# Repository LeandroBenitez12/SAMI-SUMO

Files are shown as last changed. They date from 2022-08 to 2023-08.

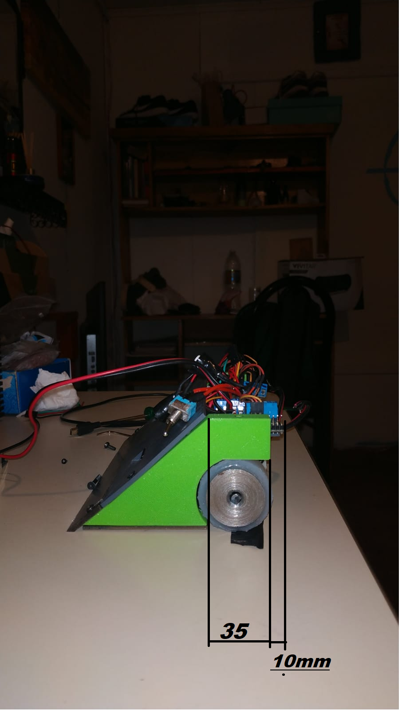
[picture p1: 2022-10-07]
Hardware/Samilateral.png

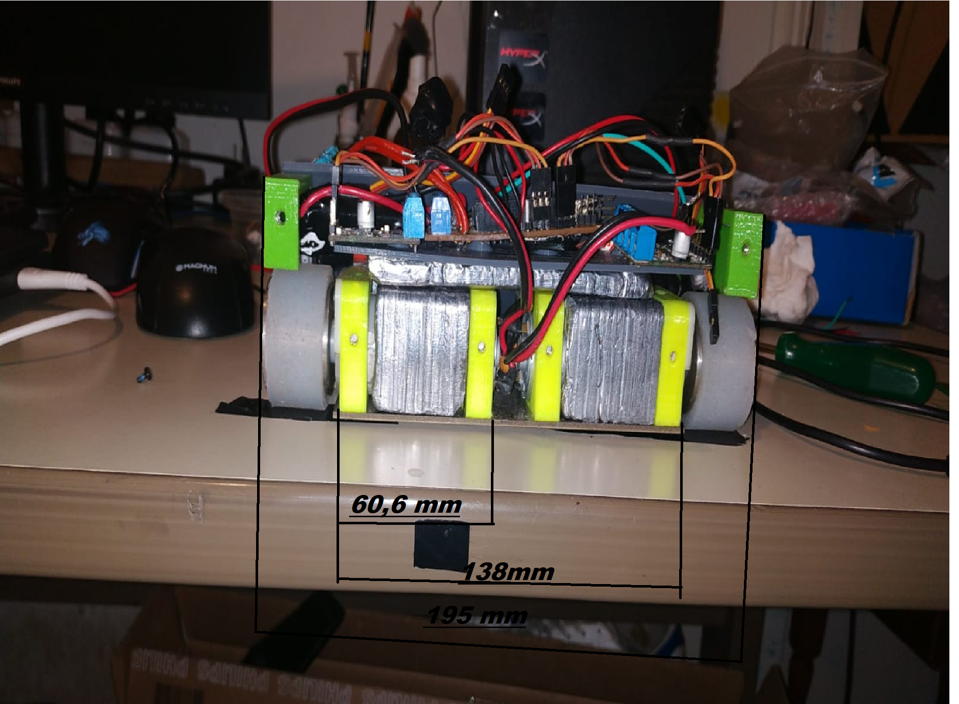
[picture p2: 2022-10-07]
Hardware/Sami.png

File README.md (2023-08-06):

# Robot Sumo Sami 🤖🏆

Sami Robot

## Descripción del Proyecto

Este repositorio contiene el código y los recursos utilizados para el desarrollo de un robot Sumo llamado Sami.

El proyecto fue iniciado en 2022 por un grupo de estudiantes de Robótica del Industrial de Temperley, Buenos Aires, Argentina, entre ellos Leandro Benitez, Ezequiel Sierra, Abril Moyano y Facundo Timwki. Contamos con la invaluable colaboración de nuestro profesor, el Ingeniero Bustos Mariano.

Sami es un robot compacto y bien equilibrado diseñado específicamente para competir en las competencias de robótica, en particular en la Liga Nacional de Robótica (LNR) en Argentina. Durante el proceso de desarrollo, logramos el título de campeones en una competencia de robótica en el Instituto Técnico Nuestra Señora De Itatí, además avanzamos en cuanto a desarrollo personal y grupal, obtuvimos experiencia en la programación, diseño de PCB, 3D, el armado de robots, y fundiendo plomo, entre otras cosas...

## Características del Robot

- **Microcontrolador ESP32** para un rendimiento potente y una amplia capacidad de conectividad.
- **Pantalla OLED** para visualizar menús y estrategias en tiempo real.
- **Drivers Pololu 24v13** para el control preciso de motores y la maniobrabilidad del robot.
- **Sensores Sharp GP2Y0A60SZLF** para detectar obstáculos y oponentes.
- **Sensores de piso QRE1113 SMD y un LDR** utilizados en diversas estrategias de detección.
- Alimentación con **2 baterías LiPo en serie de 3 celdas**, logrando una tensión de 24V.
- Uso de un **convertidor Step-Down** para bajar la tensión y alimentar el microcontrolador.

## Estructura del Repositorio

- **/Software:** Contiene el código de programación en C++ para el robot Sami, basado en el entorno Arduino, y las librerías personalizadas.
- **/Hardware:** Incluye el diseño 3D del robot Sami, así como recursos relacionados con el armado físico y moldeado de plomo para alcanzar el límite de peso en la competencia.

## Instrucciones de Uso

1. Clona el repositorio en tu computadora local para acceder a todos los recursos y el código.
2. Explora el contenido de **/Software** para conocer la programación del robot y las diferentes estrategias disponibles.
3. Consulta el diseño 3D y la información en **/Hardware** para comprender la estructura y los componentes utilizados.

## Cómo Contribuir

¡Valoramos y agradecemos cualquier contribución que puedas brindar para mejorar nuestro robot Sami! Si deseas colaborar, sugerir mejoras o corregir problemas, sigue estos pasos:

1. Haz un fork de este repositorio y clona tu copia localmente.
2. Realiza los cambios y mejoras en tu rama, incluso si es para sugerir posibles soluciones o nuevas ideas.
3. Asegúrate de agregar o actualizar la documentación con tus contribuciones.
4. Realiza un pull request a nuestra rama principal para que podamos revisar y considerar tus aportes.













y videos....

https://github.com/LeandroBenitez12/SAMI_RBSUMO/assets/108737751/56b0725f-8328-4741-986b-e7431d0c3679

## Contacto

¡Nos encantaría recibir tus comentarios, sugerencias y cualquier tipo de feedback que nos ayude a mejorar nuestro proyecto Sami! Si deseas ponerte en contacto con nosotros, no dudes en escribirnos a:

- Leandro Benitez: leandrobenitezz2004@gmail.com
- Ezequiel Sierra: Sierraezequiel75@gmail.com

## Agradecimientos

Queremos expresar nuestro agradecimiento a todas las personas que nos han brindado apoyo y colaboración en este proyecto. ¡Sin su ayuda, no habríamos llegado tan lejos en el desarrollo de Sami y en nuestras competencias!

¡Estamos entusiasmados con los avances logrados hasta el momento y esperamos seguir mejorando y refinando nuestro robot Sumo Sami en el futuro! 🤖🏆

¡Gracias por tu interés en nuestro proyecto! Si necesitas más información o tienes otras preguntas, no dudes en hacérmelas. ¡Éxito en tus futuras competencias de robótica!

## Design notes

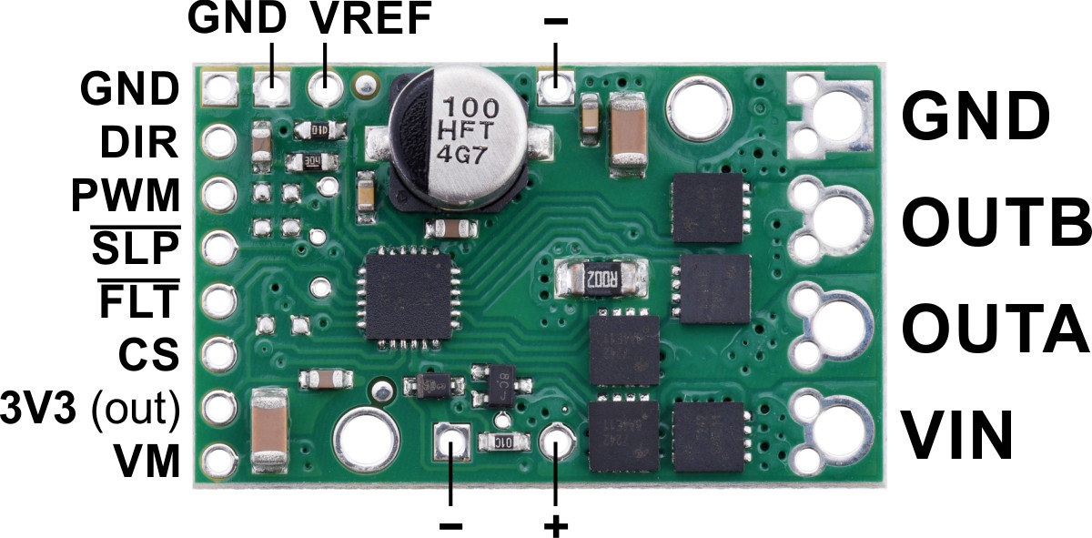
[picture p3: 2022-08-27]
Hardware/PCB V2/0J6859.1200.jpg

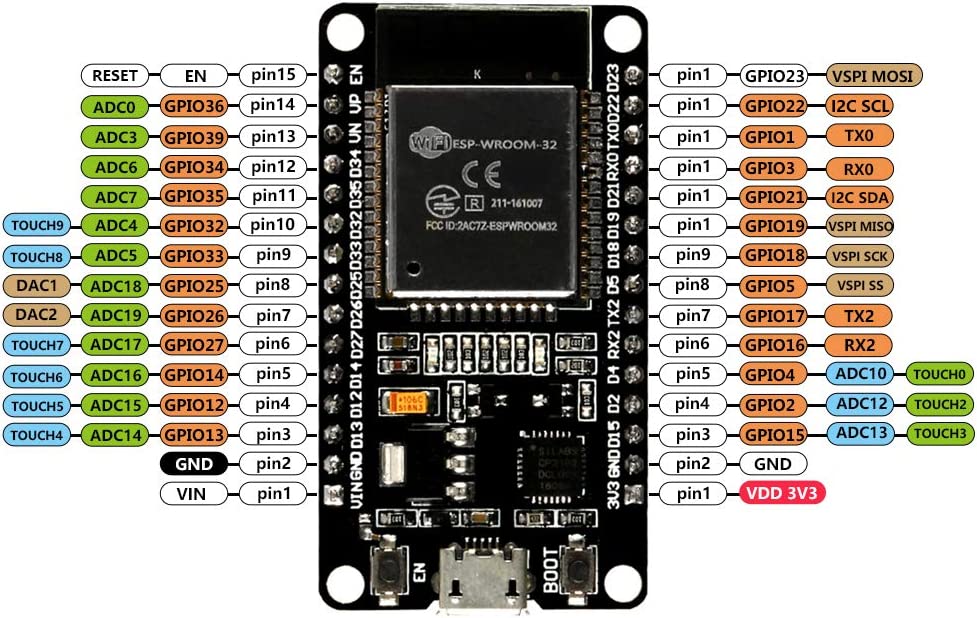
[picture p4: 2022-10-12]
Hardware/PCB V3 - Leandro/PCB V3 - Leandro/ESP32 30PINES.jpg

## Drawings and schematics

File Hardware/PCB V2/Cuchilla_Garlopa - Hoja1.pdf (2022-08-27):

E E

F F

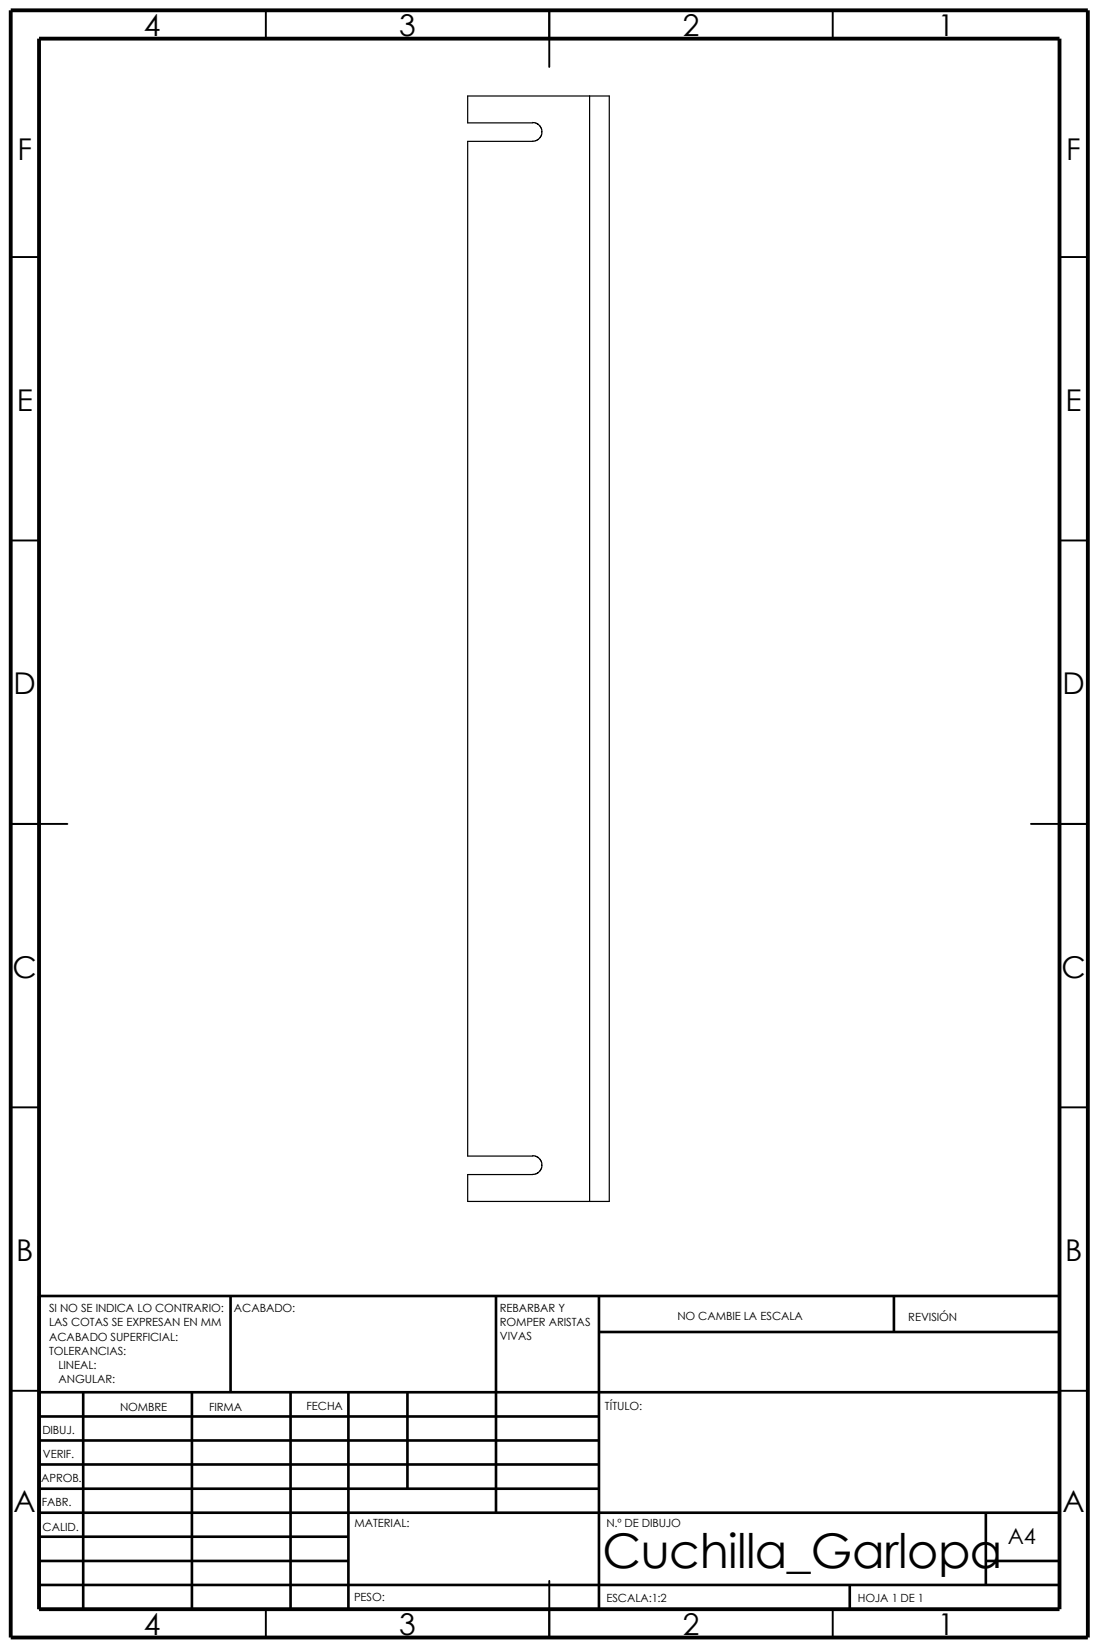
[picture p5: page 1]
PESO:; FABR.; ESCALA:1:2; HOJA 1 DE 1; N.º DE DIBUJO; REVISIÓN; CALID.; ACABADO:; VIVAS; MATERIAL:; REBARBAR Y ROMPER ARISTAS; Cuchilla_Garlopa

NO CAMBIE LA ESCALA SI NO SE INDICA LO CONTRARIO:
LAS COTAS SE EXPRESAN EN MM
ACABADO SUPERFICIAL:
TOLERANCIAS:
LINEAL:
ANGULAR:

NOMBRE | FIRMA | FECHA | TÍTULO:

DIBUJ.

VERIF.

APROB.

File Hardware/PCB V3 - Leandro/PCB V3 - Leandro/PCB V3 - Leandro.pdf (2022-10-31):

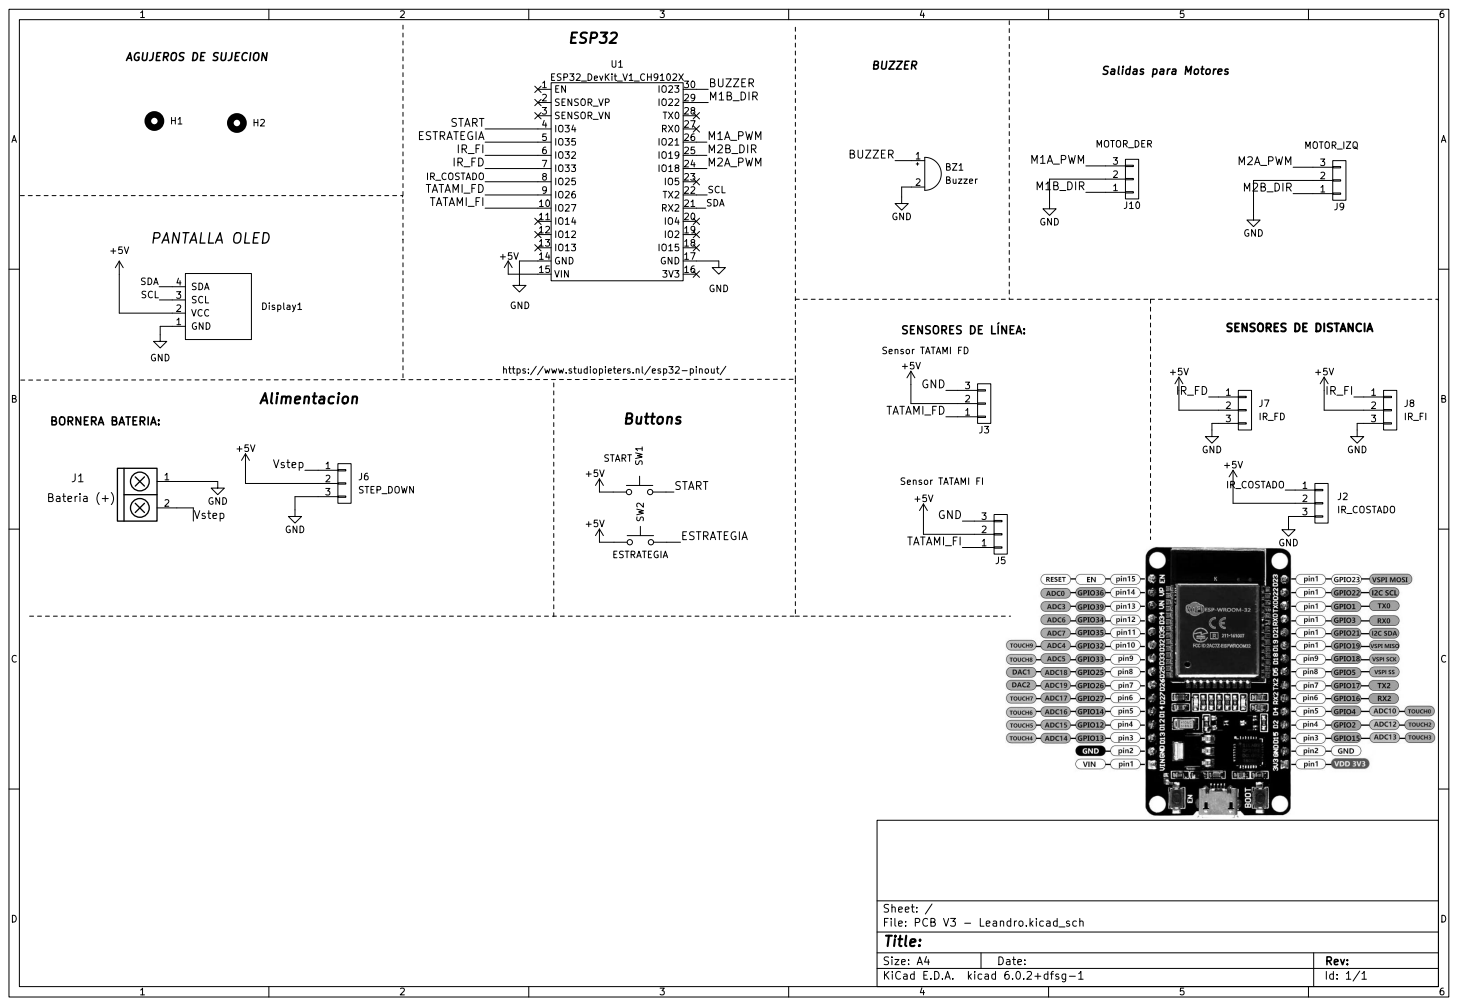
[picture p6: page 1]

þÿSENSORES DE LÍNEA: AGUJEROS DE SUJECION

https://www.studiopieters.nl/esp32-pinout/

File: PCB V3 - Leandro.kicad_sch Sheet: /
Id: 1/1 Title:

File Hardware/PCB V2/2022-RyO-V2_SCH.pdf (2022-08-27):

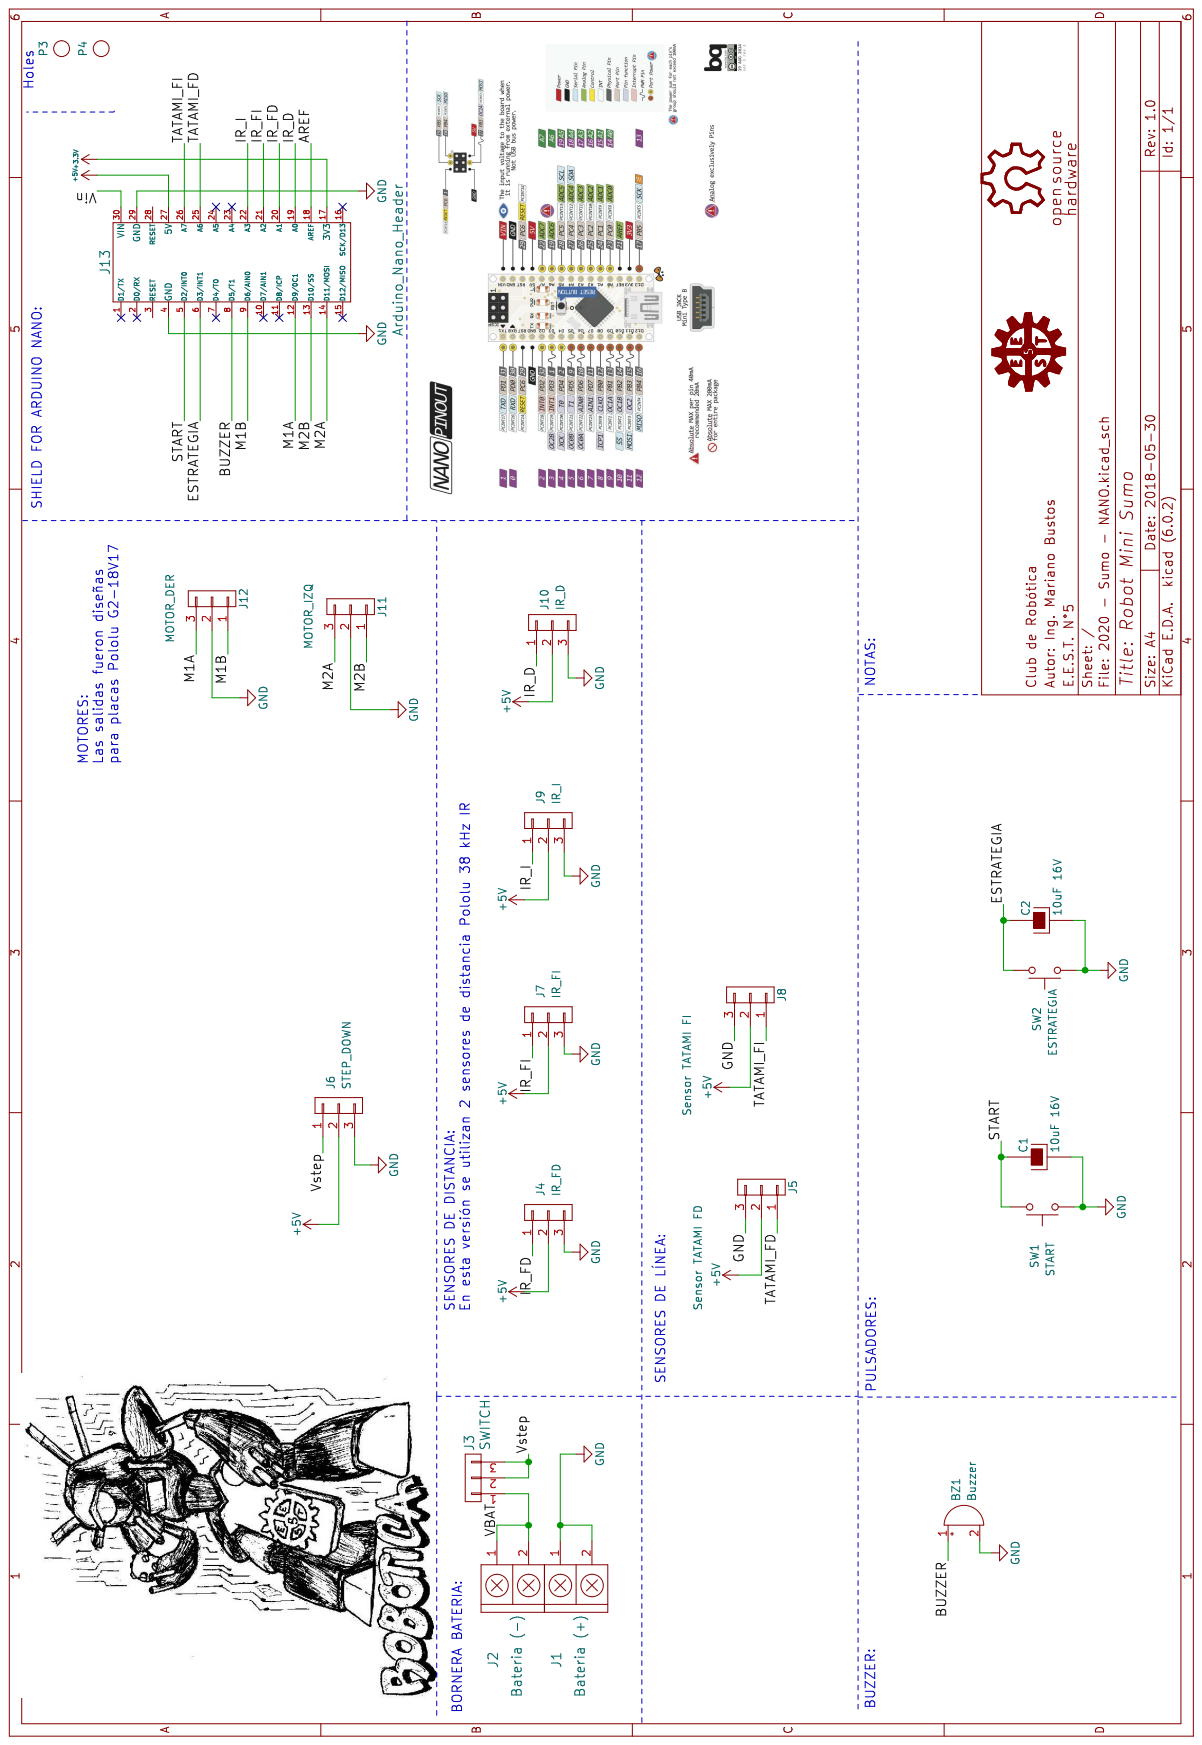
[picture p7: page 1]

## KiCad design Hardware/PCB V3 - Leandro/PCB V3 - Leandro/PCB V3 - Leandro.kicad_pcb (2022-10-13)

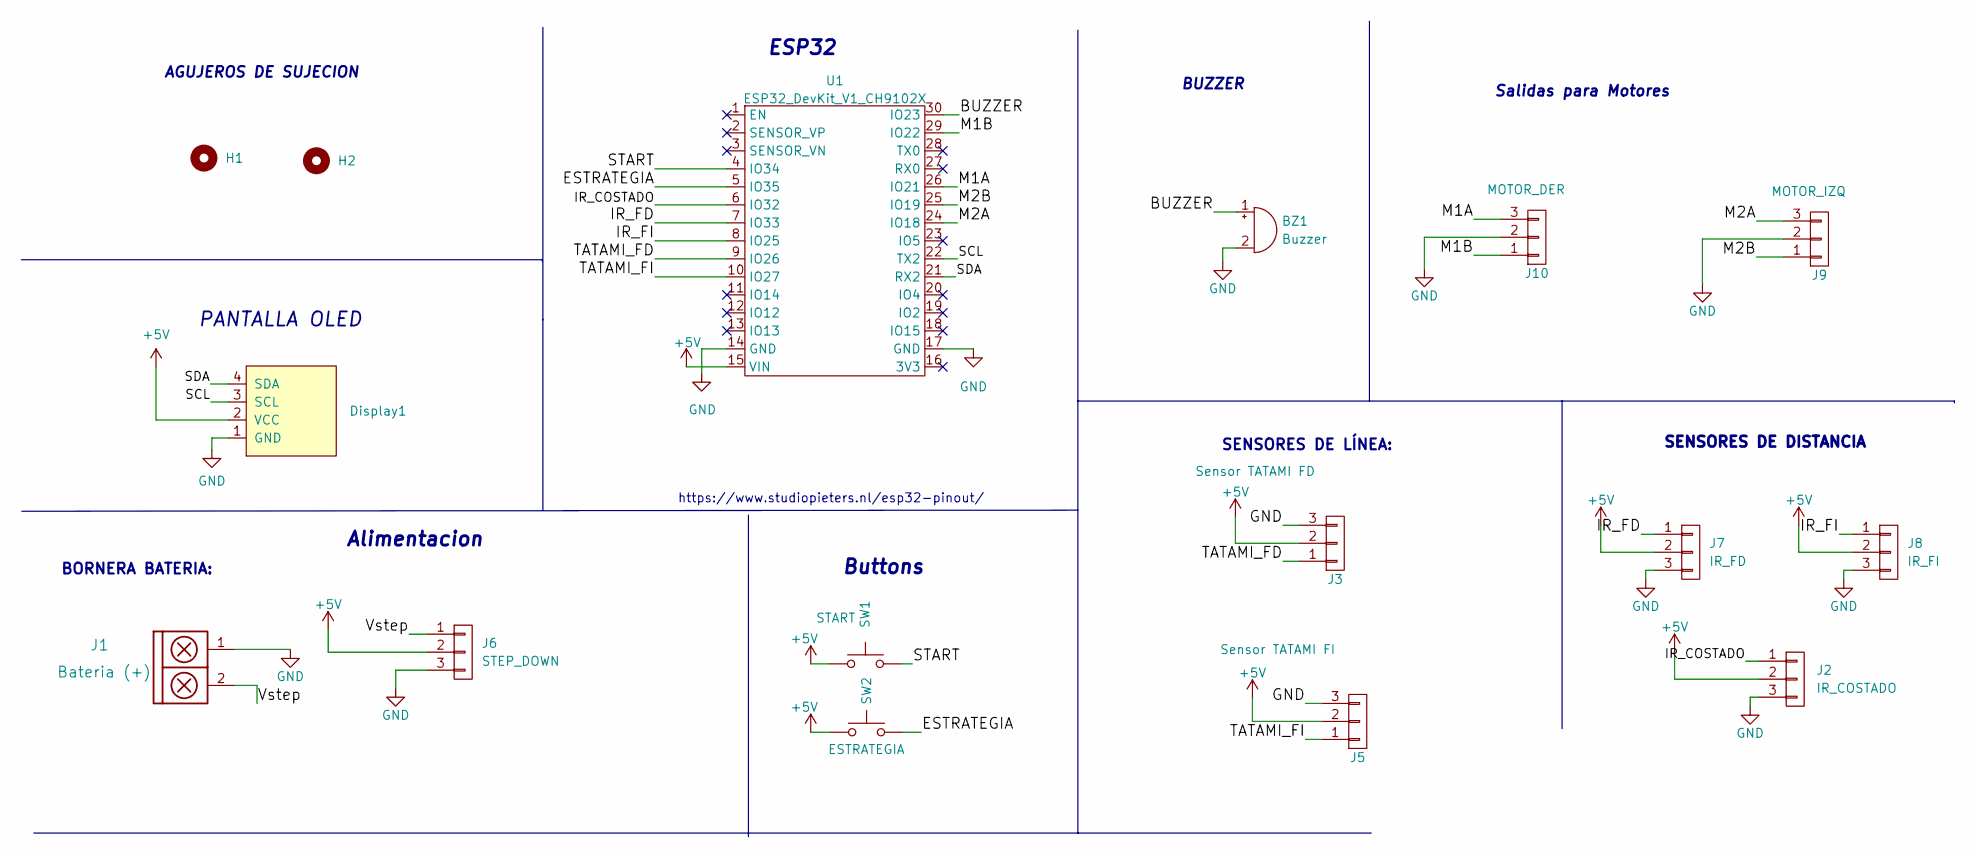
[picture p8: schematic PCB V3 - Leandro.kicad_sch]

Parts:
BZ1: Buzzer; Pin_strip_2
Display1: SSD1306-SSD1306-128x64_OLED; 128x64OLED
H1, H2: Mounting_Hole; pad_3mm
J1: Bateria (+); BORNERA2_AZUL
J2: IR_COSTADO; Pin_Strip_3
J3: Sensor TATAMI FD; Pin_Strip_3
J5: Sensor TATAMI FI; Pin_Strip_3
J6: STEP_DOWN; Pin_Strip_3
J7: IR_FD; Pin_Strip_3
J8: IR_FI; Pin_Strip_3
J9: MOTOR_IZQ; Pin_Strip_3
J10: MOTOR_DER; Pin_Strip_3
SW1: START; Pin_Header_2
SW2: ESTRATEGIA; Pin_Header_2
U1: ESP32_DevKit_V1_CH9102X

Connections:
+5V: Display1.2 (VCC), J2.2, J3.2, J5.2, J6.2, J7.2, J8.2, SW1.1, SW2.1, U1.15 (VIN)
/BUZZER: BZ1.1 (-), U1.30 (IO23)
/ESTRATEGIA: SW2.2, U1.5 (IO35)
/IR_COSTADO: J2.1, U1.6 (IO32)
/IR_FD: J7.1, U1.7 (IO33)
/IR_FI: J8.1, U1.8 (IO25)
/M1A: J10.3, U1.26 (IO21)
/M1B: J10.1, U1.29 (IO22)
/M2A: J9.3, U1.24 (IO18)
/M2B: J9.1, U1.25 (IO19)
/SCL: Display1.3 (SCL), U1.22 (TX2)
/SDA: Display1.4 (SDA), U1.21 (RX2)
/START: SW1.2, U1.4 (IO34)
/TATAMI_FD: J3.1, U1.9 (IO26)
/TATAMI_FI: J5.1, U1.10 (IO27)
/Vstep: J1.2, J6.1
GND: BZ1.2 (+), Display1.1 (GND), J1.1, J2.3, J3.3, J5.3, J6.3, J7.3, J8.3, J9.2, J10.2, U1.14 (GND), U1.17 (GND)

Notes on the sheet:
SENSORES DE LÍNEA:
Buttons
ESP32
BORNERA BATERIA:
https://www.studiopieters.nl/esp32-pinout/
PANTALLA OLED
Alimentacion
SENSORES DE DISTANCIA
AGUJEROS DE SUJECION
Salidas para Motores
BUZZER

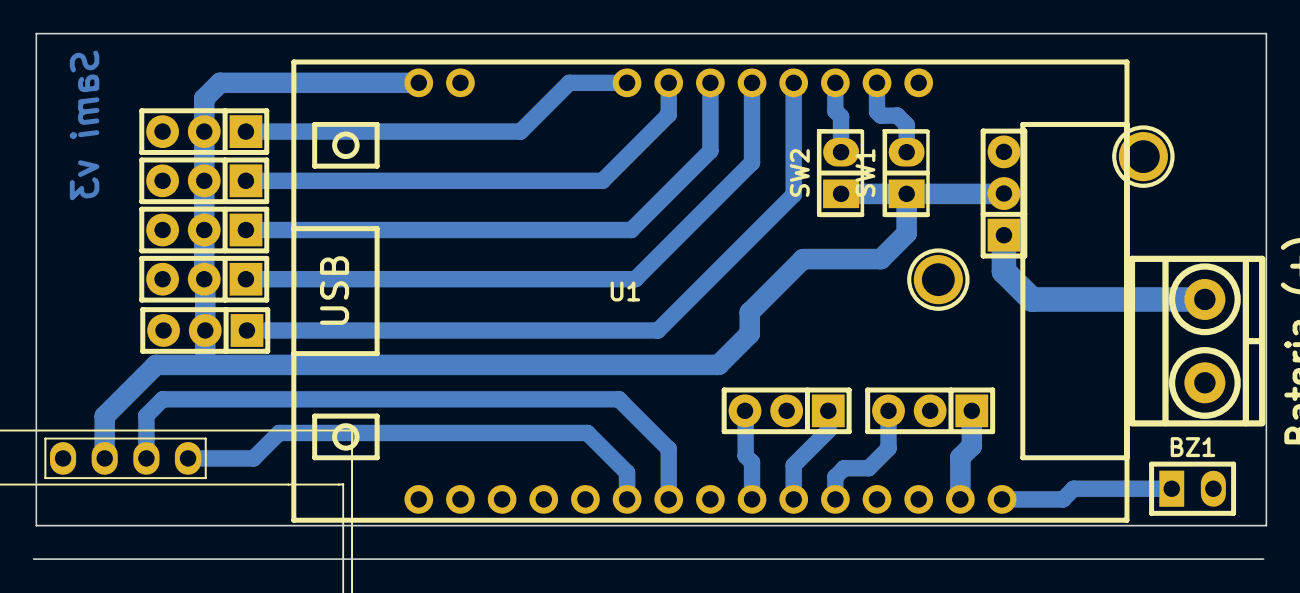
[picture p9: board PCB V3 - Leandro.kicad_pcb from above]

Board: 2 copper layers, 75.2 x 32.0 mm, 16 parts (0 on the bottom side), 17 nets.

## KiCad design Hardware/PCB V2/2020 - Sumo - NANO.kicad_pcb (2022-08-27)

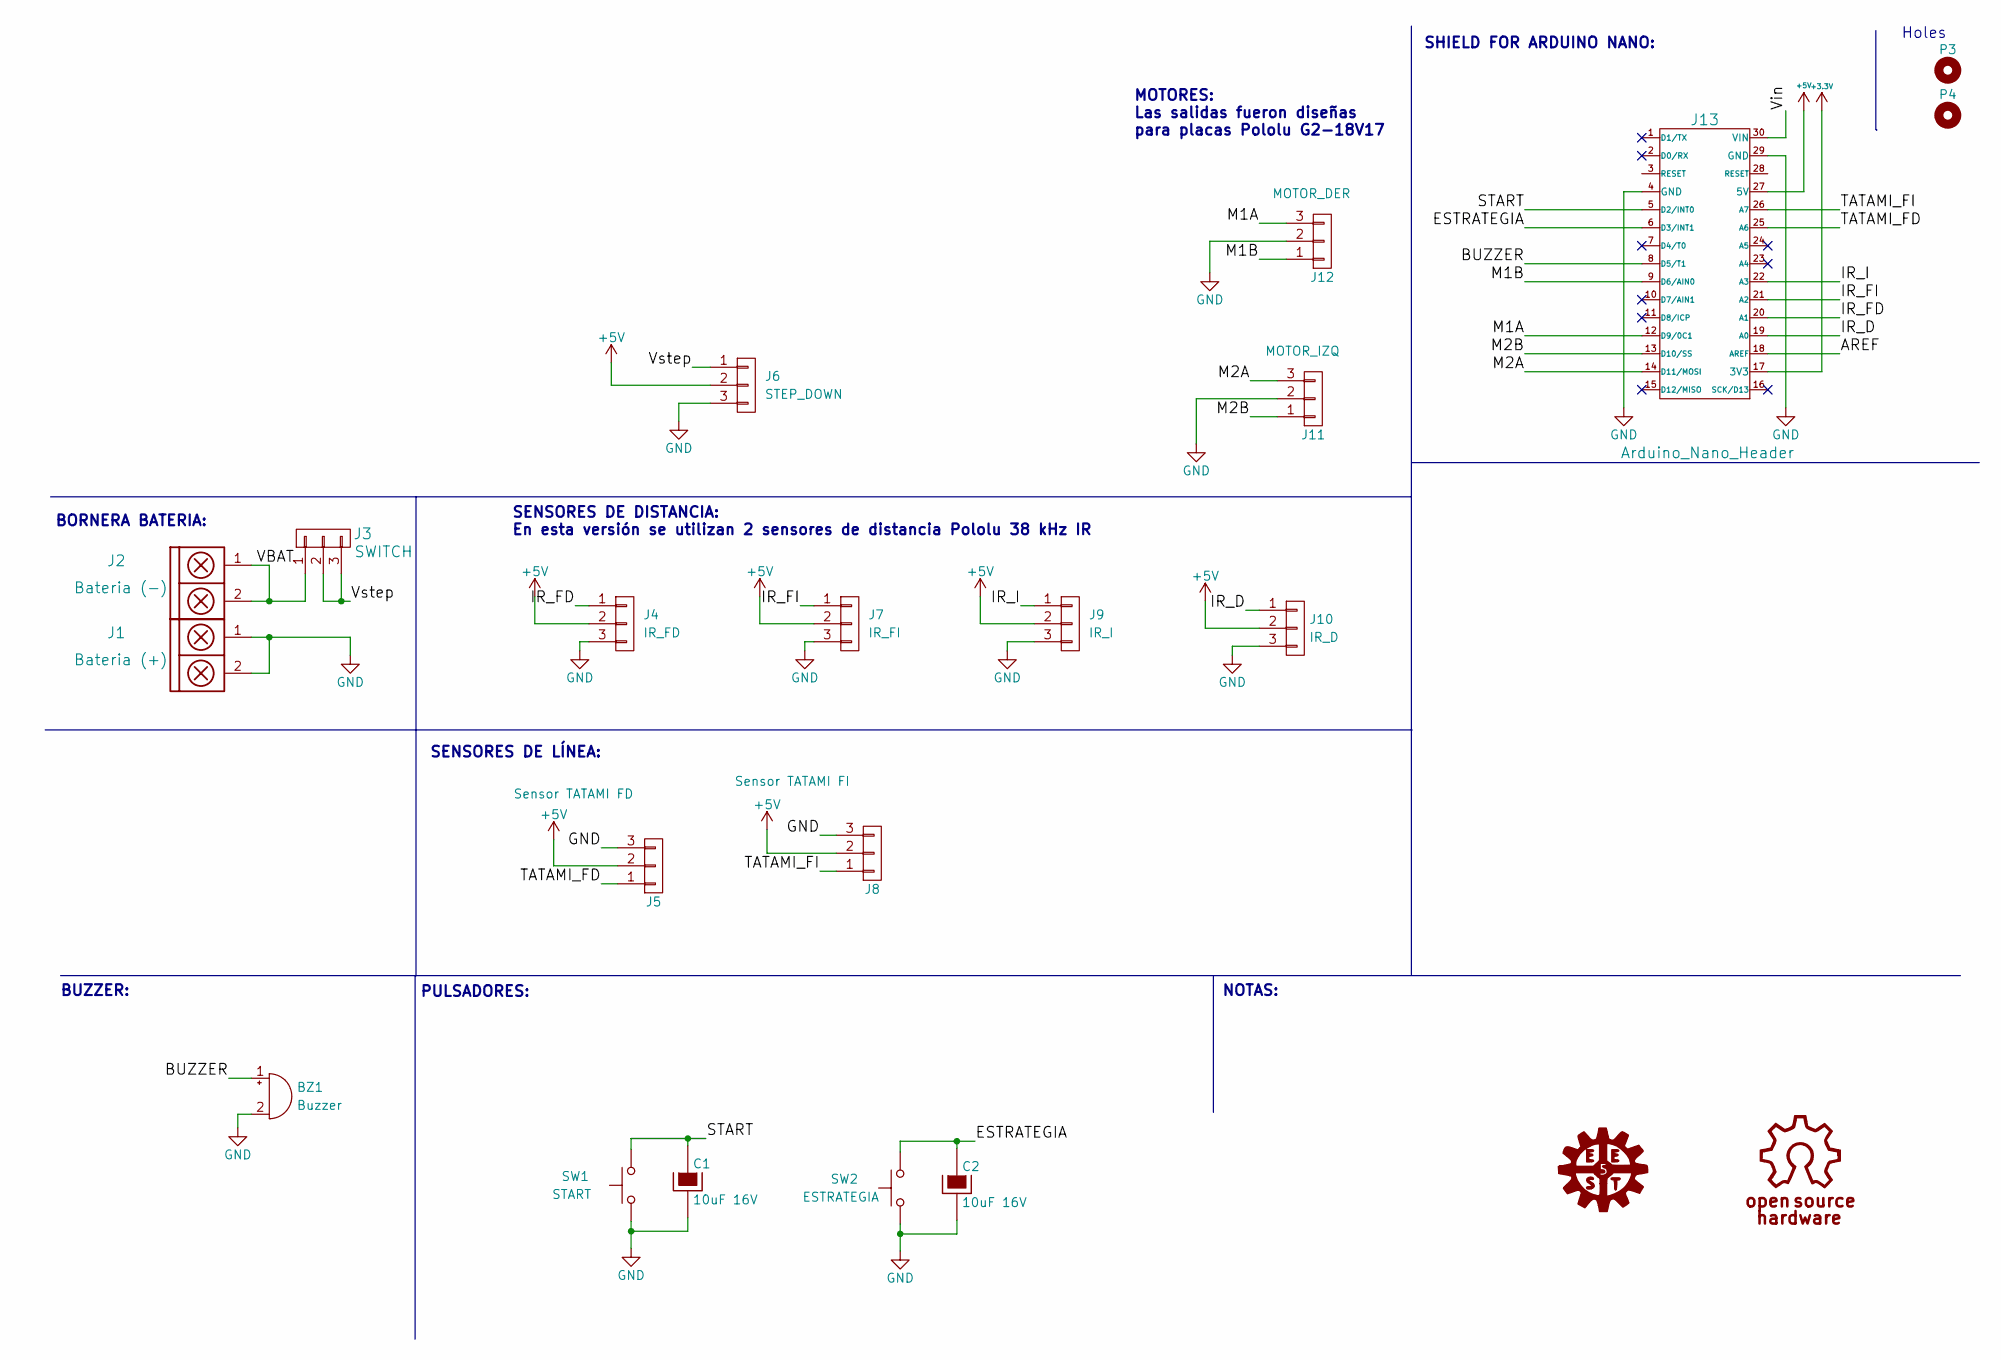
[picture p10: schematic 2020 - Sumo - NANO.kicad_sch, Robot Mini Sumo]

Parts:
BZ1: Buzzer; Pin_strip_2
C1, C2: 10uF 16V; CAP_TAN_A
J1: Bateria (+); BORNERA2_AZUL
J2: Bateria (-); BORNERA2_AZUL
J3: SWITCH; SW_SPDT_TH_Vertical
J4: IR_FD; Pin_Strip_3
J5: Sensor TATAMI FD; Pin_Strip_3
J6: STEP_DOWN; Pin_Strip_3
J7: IR_FI; Pin_Strip_3
J8: Sensor TATAMI FI; Pin_Strip_3
J9: IR_I; Pin_Strip_3
J10: IR_D; Pin_Strip_3
J11: MOTOR_IZQ; Pin_Strip_3
J12: MOTOR_DER; Pin_Strip_3
J13: Arduino_Nano_Header; arduino_nano_header
P3, P4: Mounting_Hole; Separador_M3_5mm
SW1: START; Pin_Header_2
SW2: ESTRATEGIA; Pin_Header_2

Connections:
+3V3: J13.17 (3V3)
+5V: J4.2, J5.2, J6.2, J7.2, J8.2, J9.2, J10.2, J13.27 (5V)
/AREF: J13.18 (AREF)
/BUZZER: BZ1.1 (-), J13.8 (D5/T1)
/ESTRATEGIA: C2.1, J13.6 (D3/INT1), SW2.2
/IR_D: J10.1, J13.19 (A0)
/IR_FD: J4.1, J13.20 (A1)
/IR_FI: J7.1, J13.21 (A2)
/IR_I: J9.1, J13.22 (A3)
/M1A: J12.3, J13.12 (D9/0C1)
/M1B: J12.1, J13.9 (D6/AIN0)
/M2A: J11.3, J13.14 (D11/MOSI)
/M2B: J11.1, J13.13 (D10/SS)
/START: C1.1, J13.5 (D2/INT0), SW1.2
/TATAMI_FD: J5.1, J13.25 (A6)
/TATAMI_FI: J8.1, J13.26 (A7)
/VBAT: J2.1, J2.2, J3.1
/Vin: J13.30 (VIN)
/Vstep: J3.2, J3.3, J6.1
GND: BZ1.2 (+), C1.2, C2.2, J1.1, J1.2, J4.3, J5.3, J6.3, J7.3, J8.3, J9.3, J10.3, J11.2, J12.2, J13.4 (GND), J13.29 (GND), SW1.1, SW2.1

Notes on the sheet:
SENSORES DE LÍNEA:
MOTORES: Las salidas fueron diseñas para placas Pololu G2-18V17
Holes
BORNERA BATERIA:
NOTAS:
BUZZER:
SHIELD FOR ARDUINO NANO:
SENSORES DE DISTANCIA: En esta versión se utilizan 2 sensores de distancia Pololu 38 kHz IR
PULSADORES:

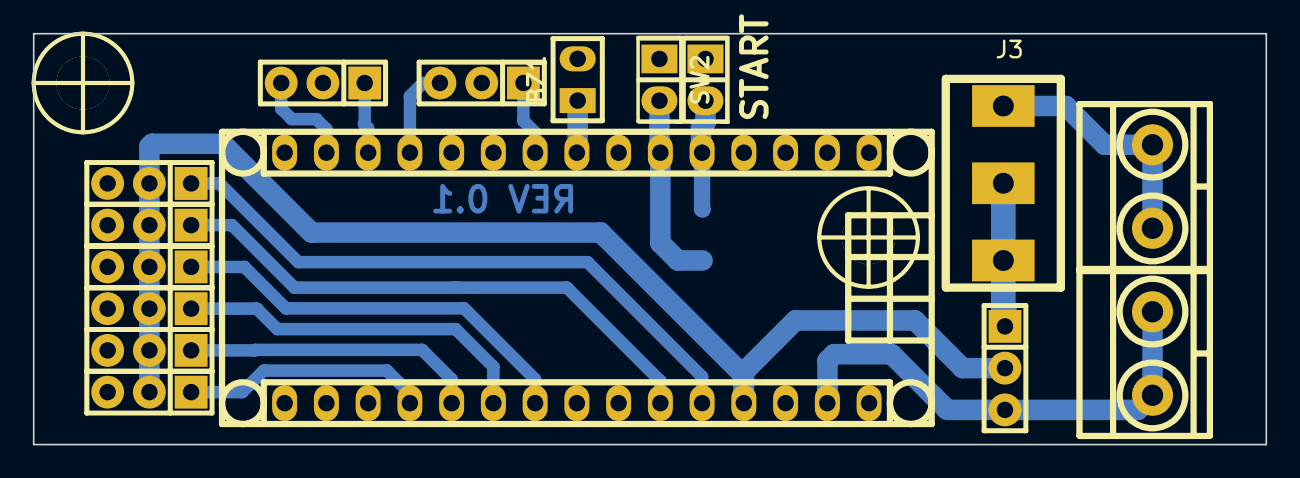
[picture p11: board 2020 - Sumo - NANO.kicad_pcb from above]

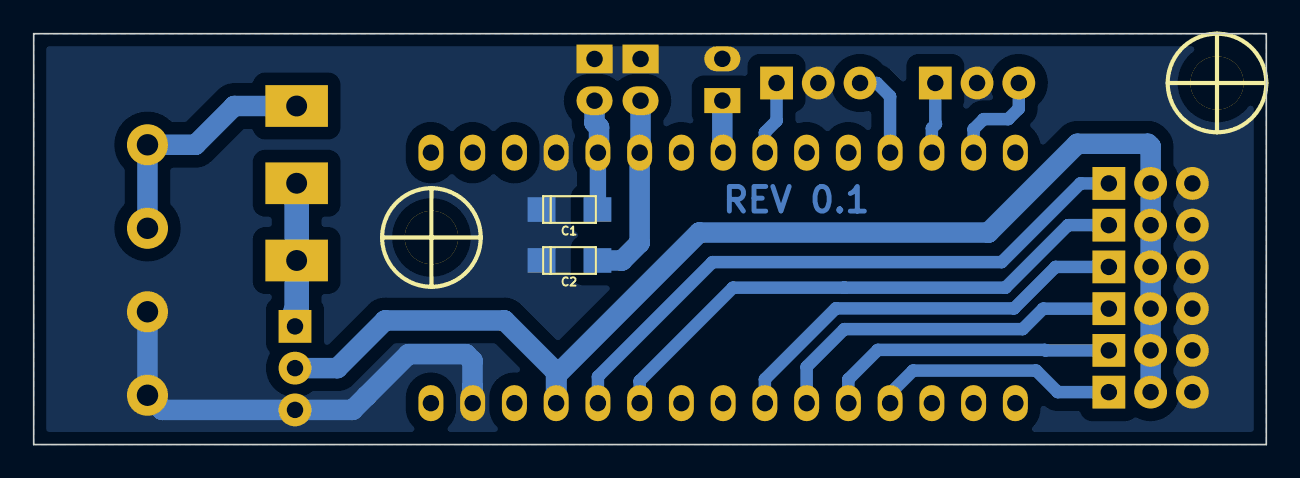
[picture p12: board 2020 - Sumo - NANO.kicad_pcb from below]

Board: 2 copper layers, 75.0 x 25.0 mm, 20 parts (2 on the bottom side), 17 nets.

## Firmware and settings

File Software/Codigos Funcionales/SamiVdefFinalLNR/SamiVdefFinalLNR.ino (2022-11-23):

//librerias
#include <Button.h>
#include <SumoEngineController.h>
#include <Tatami.h>
#include <Sharp.h>
#include "BluetoothSerial.h"
#include <SSD1306.h>

//debug
#define DEBUG_SHARP 1
#define DEBUG_TATAMI 1
#define DEBUG_STATE 1
#define DEBUG_LDR 1
#define TICK_DEBUG 500
#define TICK_DEBUG_STRATEGY 500
#define TICK_DEBUG_SHARP 500
#define TICK_DEBUG_TATAMI 500
#define TICK_DEBUG_LDR 1000
unsigned long currentTimeSharp = 0;
unsigned long currentTimeTatami = 0;
unsigned long currentTimeEstrategy = 0;
unsigned long currentTimeLdr = 0;

//configuramos el Serial Bluetooth
#if !defined(CONFIG_BT_ENABLED) || !defined(CONFIG_BLUEDROID_ENABLED)
#error Bluetooth is not enabled! Please run `make menuconfig` to and enable it
#endif
BluetoothSerial SerialBT;

//Variables y constantes para los sensores de tatami
#define PIN_SENSOR_TATAMI_IZQ 33
#define PIN_SENSOR_TATAMI_DER 25
int righTatamiRead;
int leftTatamiRead;
#define BORDE_TATAMI 300

//Variables y constantes para los sensores de distancia
#define PIN_SENSOR_DISTANCIA_DERECHO 26
#define PIN_SENSOR_DISTANCIA_IZQUIERDO 27

#define RIVAL 35
int distSharpRigh;
int distSharpLeft;

// Variables y constantes para los motores
#define PIN_ENGINE_DIR_LEFT 22 //DIR
#define PIN_ENGINE_PWM_LEFT 21 //PWM
#define PIN_ENGINE_DIR_RIGHT 19 //DIR
#define PIN_ENGINE_PWM_RIGHT 18 //PWM
#define SEARCH_SPEED 75// 12 volt 170
#define ATTACK_SPEED_LDR 255// 12 volt 255
#define ATTACK_SPEED 180// 12 volt 220
#define STRONG_ATTACK_SPEED 210
#define ATTACK_SPEED_AGGRESSIVE 240// 12 volt 235
#define AVERAGE_SPEED 100// 12 volt 200
#define TICK_AMAGUE_RONALDDINHO 200
int slowAttack = 40; // 12 volt 120
int lowAttackCont;
unsigned long currentTimeAttack = 0;
int tickTurn;
#define TICK_LOW_ATTACK 1600
#define TICK_ATTACK_SEARCH 1500
#define TICK_TURN_FRONT 59// 12 volt 115 45°
#define TICK_TURN_SIDE 95// 12 volt 168 90°
#define TICK_SHORT_BACK_TURN 115// 12 volt 200 110°
#define TICK_LONG_BACK_TURN 120// 12 volt 135°
unsigned long currentTimeAgressivveAttack = 0;
int tickAgressivveAttack;


//Variables y constantes LDR
#define PIN_SENSOR_LDR 32
#define MONTADO 100
int ldr;

//Pines para los botones
#define PIN_BUTTON_START 34
#define PIN_BUTTON_STRATEGY 35

// variables y constantes para la pantalla oled
#define PIN_SDA 16
#define PIN_SCL 17
//<------------------------------------------------------------------------------------------------------------->//
//Instanciamos todos los objetos del robot
SSD1306 display (0x3C,PIN_SDA, PIN_SCL); // inicializa pantalla con direccion 0x3C

EngineController *Sami = new EngineController(PIN_ENGINE_DIR_RIGHT, PIN_ENGINE_PWM_RIGHT, PIN_ENGINE_DIR_LEFT, PIN_ENGINE_PWM_LEFT);

Tatami *rightTatami = new Tatami(PIN_SENSOR_TATAMI_DER);
Tatami *LeftTatami = new Tatami(PIN_SENSOR_TATAMI_IZQ);

Sharp *sharpRight = new Sharp(PIN_SENSOR_DISTANCIA_DERECHO);
Sharp *sharpLeft = new Sharp(PIN_SENSOR_DISTANCIA_IZQUIERDO);

Button *selectStrategy = new  Button(PIN_BUTTON_STRATEGY);
Button *start = new  Button(PIN_BUTTON_START);
//<------------------------------------------------------------------------------------------------------------->//
//Sensor LDR
int LdrRead(int p){
  int lectura(analogRead(p));
  return lectura;
}
//<------------------------------------------------------------------------------------------------------------->//
//Funcion para imprimir la distancia que leen los sharps en el puerto Bluetooth
void printLdr()
{
  if (millis() > currentTimeLdr + TICK_DEBUG_LDR)
  {
    currentTimeLdr = millis();
    SerialBT.print("Ldr: ");
    SerialBT.println(ldr);
  }
}
void printSharp()
{
  if (millis() > currentTimeSharp + TICK_DEBUG_SHARP)
  {
    currentTimeSharp = millis();
    SerialBT.print("Right dist: ");
    SerialBT.print(distSharpRigh);
    SerialBT.print("  //  ");
    SerialBT.print("Left dist: ");
    SerialBT.println(distSharpLeft);
  }
}
//Funcion para imprimir la lectura de los sensores de tatami en el puerto Bluetooth
void printTatami()
{
  if (millis() > currentTimeTatami + TICK_DEBUG_TATAMI)
  {
    currentTimeTatami = millis();
    SerialBT.print("Right tatami: ");
    SerialBT.print(righTatamiRead);
    SerialBT.print("  //  ");
    SerialBT.print("Left tatami: ");
    SerialBT.println(leftTatamiRead);
  }
}
//<------------------------------------------------------------------------------------------------------------->//
//Funcion para la lectura de los sensores
void sensorsReading()
  {
    distSharpRigh = sharpRight->SharpDist();
    distSharpLeft = sharpLeft->SharpDist();
    righTatamiRead = rightTatami->TatamiRead();
    leftTatamiRead = LeftTatami->TatamiRead();
  }
//<------------------------------------------------------------------------------------------------------------->//
//Con el enum reemplazamos los casos de la maquina de estado por palabras descriptivas para mejor interpretacion del codigo
enum strategy
{
  REPOSITIONING_MENU,
  STRATEGIES_MENU,
  PASSIVE,
  SEMI_PASSIVE,
  SEMI_AGGRESSIVE,
  AGGRESSIVE,
  RONALDINHO
};
int strategy = REPOSITIONING_MENU;
//<------------------------------------------------------------------------------------------------------------->//
enum passive
{
  STANDBY_PASSIVE,
  SEARCH_PASSIVE,
  TURN_RIGHT_PASSIVE,
  TURN_LEFT_PASSIVE,
  TATAMI_LIMIT_PASSIVE,
  ATTACK_PASSIVE
}; 
int passive = STANDBY_PASSIVE;
//Estrategia que espera al rival y cuando este se monta ataca
void Passive()
{
  switch (passive)
  {
    case STANDBY_PASSIVE:
    {
    Sami->Stop();
    display.clear();   
    display.drawString(19, 0, "Strategy Passive"); 
    display.drawString(0, 9, "---------------------"); 
    display.drawString(0,28, "Press Star()");
    display.display();
    if (start->GetIsPress())
    {
      display.clear();
      display.display();
      delay(5000);
      Sami->Right(ATTACK_SPEED, ATTACK_SPEED);
      delay(tickTurn);
      passive = SEARCH_PASSIVE;
    } 
    break;
    }

    case SEARCH_PASSIVE:
    {
      Sami->Right(SEARCH_SPEED, SEARCH_SPEED);
      if(leftTatamiRead < 250 || righTatamiRead < 250) passive = TATAMI_LIMIT_PASSIVE;
      if(distSharpRigh <= RIVAL && distSharpLeft > RIVAL) passive = TURN_RIGHT_PASSIVE;
      if(distSharpRigh > RIVAL && distSharpLeft <= RIVAL) passive = TURN_LEFT_PASSIVE;
      if(distSharpRigh <= RIVAL && distSharpLeft <= RIVAL) passive = ATTACK_PASSIVE;
      break;    
    }

    case TURN_RIGHT_PASSIVE:
    {
      Sami->Right(SEARCH_SPEED, SEARCH_SPEED);
      if(leftTatamiRead < 250 || righTatamiRead < 250) passive = TATAMI_LIMIT_PASSIVE;
      if(distSharpRigh > RIVAL && distSharpLeft > RIVAL) passive = SEARCH_PASSIVE;
      if(distSharpRigh > RIVAL && distSharpLeft <= RIVAL) passive = TURN_LEFT_PASSIVE;
      if(distSharpRigh <= RIVAL && distSharpLeft <= RIVAL) passive = ATTACK_PASSIVE;
      break;
    }

    case TURN_LEFT_PASSIVE:
    {
      Sami->Left(SEARCH_SPEED, SEARCH_SPEED);
      if(leftTatamiRead < 250 || righTatamiRead < 250) passive = TATAMI_LIMIT_PASSIVE;
      if(distSharpRigh > RIVAL && distSharpLeft > RIVAL) passive = SEARCH_PASSIVE;
      if(distSharpRigh <= RIVAL && distSharpLeft > RIVAL) passive = TURN_RIGHT_PASSIVE;
      if(distSharpRigh <= RIVAL && distSharpLeft <= RIVAL) passive = ATTACK_PASSIVE;
      break;
    }

    case ATTACK_PASSIVE:
    {
      if(ldr < MONTADO)
      {
        Sami->Forward(ATTACK_SPEED_LDR, ATTACK_SPEED_LDR);
        if(leftTatamiRead < 250 || righTatamiRead < 250) passive = TATAMI_LIMIT_PASSIVE;
      }

      else 
      {
        Sami->Stop();
        if(distSharpRigh > RIVAL && distSharpLeft > RIVAL) passive = SEARCH_PASSIVE;
        if(distSharpRigh <= RIVAL && distSharpLeft > RIVAL) passive = TURN_RIGHT_PASSIVE;
        if(distSharpRigh > RIVAL && distSharpLeft <= RIVAL) passive = TURN_LEFT_PASSIVE;
      }
      break;
    }

    case TATAMI_LIMIT_PASSIVE: 
    {
    Sami->Backward(AVERAGE_SPEED, AVERAGE_SPEED);
    delay(300);
    if(leftTatamiRead > 250 && righTatamiRead > 250) passive = SEARCH_PASSIVE;
    break;
    }
  }
}
//<------------------------------------------------------------------------------------------------------------->//
enum semiPassive
{
  STANDBY_SEMI_PASSIVE,
  SEARCH_SEMI_PASSIVE,
  TURN_RIGHT_SEMI_PASSIVE,
  TURN_LEFT_SEMI_PASSIVE,
  LOW_ATTACK_SEMI_PASSIVE,
  TATAMI_LIMIT_SEMI_PASSIVE,
  ATTACK_SEMI_PASSIVE
}; 
int semiPassive = STANDBY_SEMI_PASSIVE;
//Estrategia que espera al rival y avanza de a poco buscando el rival
void SemiPassive()
{
  switch (semiPassive)
  {
    case STANDBY_SEMI_PASSIVE:
    {
    Sami->Stop();
    display.clear();   
    display.drawString(19, 0, "Strategy Semi-Passive"); 
    display.drawString(0, 9, "---------------------"); 
    display.drawString(0,28, "Press Star()");
    display.display();
    if (start->GetIsPress())
    {
      display.clear();
      display.display();
      delay(5000);
      Sami->Right(ATTACK_SPEED_LDR, ATTACK_SPEED_LDR);
      delay(tickTurn);
      semiPassive = SEARCH_SEMI_PASSIVE;
    } 
    break;
    }

    case SEARCH_SEMI_PASSIVE:
    {
      Sami->Right(SEARCH_SPEED, SEARCH_SPEED);
      if(leftTatamiRead < 250 || righTatamiRead < 250) semiPassive = TATAMI_LIMIT_SEMI_PASSIVE;
      if(distSharpRigh <= RIVAL && distSharpLeft > RIVAL) semiPassive = TURN_RIGHT_SEMI_PASSIVE;
      if(distSharpRigh > RIVAL && distSharpLeft <= RIVAL) semiPassive = TURN_LEFT_SEMI_PASSIVE;
      if(distSharpRigh <= RIVAL && distSharpLeft <= RIVAL) semiPassive = ATTACK_SEMI_PASSIVE;
      if (millis() > currentTimeAttack + TICK_ATTACK_SEARCH)
      {
        semiPassive = LOW_ATTACK_SEMI_PASSIVE;
      }
      if(ldr < MONTADO)
      {
        Sami->Forward(ATTACK_SPEED, ATTACK_SPEED);
        if(leftTatamiRead < 250 || righTatamiRead < 250) semiPassive = TATAMI_LIMIT_SEMI_PASSIVE;
      }
      break;    
    }

    case TURN_RIGHT_PASSIVE:
    {
      Sami->Right(SEARCH_SPEED, SEARCH_SPEED);
      if(leftTatamiRead < 250 || righTatamiRead < 250) semiPassive = TATAMI_LIMIT_SEMI_PASSIVE;
      if(distSharpRigh > RIVAL && distSharpLeft > RIVAL) semiPassive = SEARCH_SEMI_PASSIVE;
      if(distSharpRigh > RIVAL && distSharpLeft <= RIVAL) semiPassive = TURN_LEFT_SEMI_PASSIVE;
      if(distSharpRigh <= RIVAL && distSharpLeft <= RIVAL) semiPassive = ATTACK_SEMI_PASSIVE;
      if(ldr < MONTADO)
      {
        Sami->Forward(ATTACK_SPEED, ATTACK_SPEED);
        if(leftTatamiRead < 250 || righTatamiRead < 250) semiPassive = TATAMI_LIMIT_SEMI_PASSIVE;
      }
      break;
    }

    case TURN_LEFT_PASSIVE:
    {
      Sami->Left(SEARCH_SPEED, SEARCH_SPEED);
      if(leftTatamiRead < 250 || righTatamiRead < 250) semiPassive = TATAMI_LIMIT_SEMI_PASSIVE;
      if(distSharpRigh > RIVAL && distSharpLeft > RIVAL) semiPassive = SEARCH_SEMI_PASSIVE;
      if(distSharpRigh <= RIVAL && distSharpLeft > RIVAL) semiPassive = TURN_RIGHT_SEMI_PASSIVE;
      if(distSharpRigh <= RIVAL && distSharpLeft <= RIVAL) semiPassive = ATTACK_SEMI_PASSIVE;
      if(ldr < MONTADO)
      {
        Sami->Forward(ATTACK_SPEED, ATTACK_SPEED);
        if(leftTatamiRead < 250 || righTatamiRead < 250) semiPassive = TATAMI_LIMIT_SEMI_PASSIVE;
      }
      break;
    }

    case ATTACK_SEMI_PASSIVE:
    {
      if(ldr < MONTADO)
      {
        Sami->Forward(ATTACK_SPEED, ATTACK_SPEED);
        if(leftTatamiRead < 250 || righTatamiRead < 250) semiPassive = TATAMI_LIMIT_SEMI_PASSIVE;
      }

      else 
      {
        Sami->Stop();
        if(distSharpRigh > RIVAL && distSharpLeft > RIVAL) semiPassive = SEARCH_SEMI_PASSIVE;
        if(distSharpRigh <= RIVAL && distSharpLeft > RIVAL) semiPassive = TURN_RIGHT_SEMI_PASSIVE;
        if(distSharpRigh > RIVAL && distSharpLeft <= RIVAL) semiPassive = TURN_LEFT_SEMI_PASSIVE;
        if (millis() > currentTimeAttack + TICK_LOW_ATTACK)
        {
          semiPassive = LOW_ATTACK_SEMI_PASSIVE;
        }
      }
      break;
    }

    case LOW_ATTACK_SEMI_PASSIVE:
    {
      lowAttackCont++;
      slowAttack = slowAttack + (lowAttackCont*10);
      Sami->Forward(slowAttack, slowAttack);
      delay(388);
      currentTimeAttack = millis();
      semiPassive = ATTACK_SEMI_PASSIVE;
      break;
    }

    case TATAMI_LIMIT_SEMI_PASSIVE: 
    {
        Sami->Backward(AVERAGE_SPEED, AVERAGE_SPEED);
        delay(300);
    if(leftTatamiRead > 250 && righTatamiRead > 250) semiPassive = SEARCH_SEMI_PASSIVE;
    break;
    }
  }
}
//<------------------------------------------------------------------------------------------------------------->//
enum semiAggressive
{
  STANDBY_SEMI_AGGRESSIVE,
  SEARCH_SEMI_AGGRESSIVE,
  TURN_RIGHT_SEMI_AGGRESSIVE,
  TURN_LEFT_SEMI_AGGRESSIVE,
  TATAMI_LIMIT_SEMI_AGGRESSIVE,
  ATTACK_SEMI_AGGRESSIVE
}; 
int semiAggressive = STANDBY_SEMI_AGGRESSIVE;
//Estrategia que va a buscar al rival de forma moderada
void SemiAggressive()
{
  switch (semiAggressive)
  {
    case STANDBY_SEMI_AGGRESSIVE:
    {
    Sami->Stop();
    display.clear();   
    display.drawString(19, 0, "Strategy Semi-Aggressive"); 
    display.drawString(0, 9, "---------------------"); 
    display.drawString(0,28, "Press Star()");
    display.display();
    if (start->GetIsPress())
    {
      display.clear();
      display.display();
      delay(5000);
      Sami->Right(ATTACK_SPEED_LDR, ATTACK_SPEED_LDR);
      delay(tickTurn);
      semiAggressive = SEARCH_SEMI_AGGRESSIVE;
    } 
    break;
    }

    case SEARCH_SEMI_AGGRESSIVE:
    {
      Sami->Right(SEARCH_SPEED, SEARCH_SPEED);
      if(leftTatamiRead < 250 || righTatamiRead < 250) semiAggressive = TATAMI_LIMIT_SEMI_AGGRESSIVE;
      if(distSharpRigh <= RIVAL && distSharpLeft > RIVAL) semiAggressive = TURN_RIGHT_SEMI_AGGRESSIVE;
      if(distSharpRigh > RIVAL && distSharpLeft <= RIVAL) semiAggressive = TURN_LEFT_SEMI_AGGRESSIVE;
      if(distSharpRigh <= RIVAL && distSharpLeft <= RIVAL) semiAggressive = ATTACK_SEMI_AGGRESSIVE; 
    }

    case TURN_RIGHT_SEMI_AGGRESSIVE:
    {
      Sami->Right(SEARCH_SPEED, SEARCH_SPEED);
      if(leftTatamiRead < 250 || righTatamiRead < 250) semiAggressive = TATAMI_LIMIT_SEMI_AGGRESSIVE;
      if(distSharpRigh > RIVAL && distSharpLeft > RIVAL) semiAggressive = SEARCH_SEMI_AGGRESSIVE;
      if(distSharpRigh > RIVAL && distSharpLeft <= RIVAL) semiAggressive = TURN_LEFT_SEMI_AGGRESSIVE;
      if(distSharpRigh <= RIVAL && distSharpLeft <= RIVAL) semiAggressive = ATTACK_SEMI_AGGRESSIVE;
      break;
    }

    case TURN_LEFT_SEMI_AGGRESSIVE:
    {
      Sami->Left(SEARCH_SPEED, SEARCH_SPEED);
      if(leftTatamiRead < 250 || righTatamiRead < 250) semiAggressive = TATAMI_LIMIT_SEMI_AGGRESSIVE;
      if(distSharpRigh > RIVAL && distSharpLeft > RIVAL) semiAggressive = SEARCH_SEMI_AGGRESSIVE;
      if(distSharpRigh <= RIVAL && distSharpLeft > RIVAL) semiAggressive = TURN_RIGHT_SEMI_AGGRESSIVE;
      if(distSharpRigh <= RIVAL && distSharpLeft <= RIVAL) semiAggressive = ATTACK_SEMI_AGGRESSIVE;
      break;
    }

    case ATTACK_SEMI_AGGRESSIVE:
    {
      Sami->Forward(ATTACK_SPEED, ATTACK_SPEED);
      if(distSharpRigh > RIVAL && distSharpLeft > RIVAL) semiAggressive = SEARCH_SEMI_AGGRESSIVE;
      if(distSharpRigh <= RIVAL && distSharpLeft > RIVAL) semiAggressive = TURN_RIGHT_SEMI_AGGRESSIVE;
      if(distSharpRigh > RIVAL && distSharpLeft <= RIVAL) semiAggressive = TURN_LEFT_SEMI_AGGRESSIVE;
      if(leftTatamiRead < 250 || righTatamiRead < 250) semiPassive = TATAMI_LIMIT_SEMI_AGGRESSIVE;
      if(ldr < MONTADO) 
      {
        Sami->Forward(ATTACK_SPEED_LDR, ATTACK_SPEED_LDR);
        if(leftTatamiRead < 250 || righTatamiRead < 250) semiPassive = TATAMI_LIMIT_SEMI_AGGRESSIVE;
      }
      if(distSharpRigh > 15 && distSharpLeft > 15)
      {
        Sami->Forward(STRONG_ATTACK_SPEED, STRONG_ATTACK_SPEED);
      }
      break;
    }

    case TATAMI_LIMIT_SEMI_AGGRESSIVE: 
    {
      Sami->Backward(AVERAGE_SPEED, AVERAGE_SPEED);
      delay(300);
    if(leftTatamiRead > 250 && righTatamiRead > 250) semiAggressive = SEARCH_SEMI_AGGRESSIVE;
    break;
    }
  }
}
//<------------------------------------------------------------------------------------------------------------->//
enum aggressive
{
  STANDBY_AGGRESSIVE,
  SEARCH_AGGRESSIVE,
  TURN_RIGHT_AGGRESSIVE,
  TURN_LEFT_AGGRESSIVE,
  TATAMI_LIMIT_AGGRESSIVE,
  ATTACK_AGGRESSIVE
}; 
int aggressive = STANDBY_AGGRESSIVE;
//Estrategia que va a buscar al rival de forma moderada
void Aggressive()
{
  switch (aggressive)
  {
    case STANDBY_AGGRESSIVE:
    {
    Sami->Stop();
    display.clear();   
    display.drawString(19, 0, "Strategy Aggressive"); 
    display.drawString(0, 9, "---------------------"); 
    display.drawString(0,28, "Press Star()");
    display.display();
    if (start->GetIsPress())
    {
      display.clear();
      display.display();
      delay(5000);
      Sami->Right(ATTACK_SPEED_LDR, ATTACK_SPEED_LDR);
      delay(tickTurn);
      aggressive = SEARCH_AGGRESSIVE;
    } 
    break;
    }

    case SEARCH_AGGRESSIVE:
    {
      Sami->Right(SEARCH_SPEED, SEARCH_SPEED);
      if(leftTatamiRead < 250 || righTatamiRead < 250) semiAggressive = TATAMI_LIMIT_AGGRESSIVE;
      if(distSharpRigh <= RIVAL && distSharpLeft > RIVAL) semiAggressive = TURN_RIGHT_AGGRESSIVE;
      if(distSharpRigh > RIVAL && distSharpLeft <= RIVAL) semiAggressive = TURN_LEFT_AGGRESSIVE;
      if(distSharpRigh <= RIVAL && distSharpLeft <= RIVAL) semiAggressive = ATTACK_AGGRESSIVE; 
    }

    case TURN_RIGHT_AGGRESSIVE:
    {
      Sami->Right(SEARCH_SPEED, SEARCH_SPEED);
      if(leftTatamiRead < 250 || righTatamiRead < 250) semiAggressive = TATAMI_LIMIT_AGGRESSIVE;
      if(distSharpRigh > RIVAL && distSharpLeft > RIVAL) semiAggressive = SEARCH_AGGRESSIVE;
      if(distSharpRigh > RIVAL && distSharpLeft <= RIVAL) semiAggressive = TURN_LEFT_AGGRESSIVE;
      if(distSharpRigh <= RIVAL && distSharpLeft <= RIVAL) semiAggressive = ATTACK_AGGRESSIVE;
      break;
    }

    TURN_LEFT_AGGRESSIVE:
    {
      Sami->Left(SEARCH_SPEED, SEARCH_SPEED);
      if(leftTatamiRead < 250 || righTatamiRead < 250) semiAggressive = TATAMI_LIMIT_AGGRESSIVE;
      if(distSharpRigh > RIVAL && distSharpLeft > RIVAL) semiAggressive = SEARCH_AGGRESSIVE;
      if(distSharpRigh <= RIVAL && distSharpLeft > RIVAL) semiAggressive = TURN_RIGHT_AGGRESSIVE;
      if(distSharpRigh <= RIVAL && distSharpLeft <= RIVAL) semiAggressive = ATTACK_AGGRESSIVE;
      break;
    }


    case ATTACK_AGGRESSIVE:
    {
      Sami->Stop();
      if (millis() > currentTimeAgressivveAttack + tickAgressivveAttack)
      {
        Sami->Forward(ATTACK_SPEED_AGGRESSIVE, ATTACK_SPEED_AGGRESSIVE);
        if(distSharpRigh > RIVAL || distSharpLeft > RIVAL) aggressive = SEARCH_AGGRESSIVE;
        if(leftTatamiRead < 250 || righTatamiRead < 250) aggressive = TATAMI_LIMIT_AGGRESSIVE;
        if(ldr < MONTADO) 
        {
          Sami->Forward(ATTACK_SPEED_LDR, ATTACK_SPEED_LDR);
          if(leftTatamiRead < 250 || righTatamiRead < 250) aggressive = TATAMI_LIMIT_AGGRESSIVE;
        }
      }
      break;
    }

    case TATAMI_LIMIT_AGGRESSIVE: 
    {
    Sami->Backward(AVERAGE_SPEED, AVERAGE_SPEED);
    delay(300);
    if(leftTatamiRead > 250 && righTatamiRead > 250) aggressive = SEARCH_AGGRESSIVE;
    break;
    }
  }
}

//<------------------------------------------------------------------------------------------------------------->//
enum ronaldinho
{
  STANDBY_RONALDINHO,
  ADVANCE_RONALDINHO,
  SEARCH_RONALDINHO,
  TATAMI_LIMIT_RONALDINHO,
  ATTACK_RONALDINHO,
  LOW_ATTACK_RONALDINHO,
  TURN_RONALDINHO,
};
int ronaldinho = STANDBY_RONALDINHO;
// Estrategia que pasea por el tatami buscando que el rival se caiga solo del tatami
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
void loop(){ 
  sensorsReading();
  ldr = LdrRead(PIN_SENSOR_LDR);
  logicMovement();
  if(DEBUG_SHARP) printSharp();
  if(DEBUG_TATAMI) printTatami();
  //if(DEBUG_STATE) printStrategy();
  if(DEBUG_LDR) printLdr();
}

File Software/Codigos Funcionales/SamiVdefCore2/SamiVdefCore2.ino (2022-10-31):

//librerias
#include <Button.h>
#include <MotorSumo.h>
#include <Tatami.h>
#include <Sharp.h>
#include "BluetoothSerial.h"
#include <Wire.h>      // libreria para bus I2C
#include <Adafruit_GFX.h>   // libreria para pantallas graficas
#include <Adafruit_SSD1306.h>   // libreria para controlador SSD1306

// variable para la creacion de una nueva tare
TaskHandle_t Task1; 

//debug
#define DEBUG_SHARP 1
#define DEBUG_TATAMI 1
#define DEBUG_STATE 1
#define TICK_DEBUG 500
unsigned long currentTimeSharp = 0;
unsigned long currentTimeTatami = 0;
unsigned long currentTimeEstrategy = 0;

//configuramos el Serial Bluetooth
#if !defined(CONFIG_BT_ENABLED) || !defined(CONFIG_BLUEDROID_ENABLED)
#error Bluetooth is not enabled! Please run `make menuconfig` to and enable it
#endif
BluetoothSerial SerialBT;


//Variables y constantes para los sensores de tatami
#define PIN_SENSOR_TATAMI_IZQ 26
#define PIN_SENSOR_TATAMI_DER 27
int righTatamiRead;
int leftTatamiRead;
#define BORDE_TATAMI 300

//Variables y constantes para los sensores de distancia
#define PIN_SENSOR_DISTANCIA_DERECHO 32
#define PIN_SENSOR_DISTANCIA_IZQUIERDO 33
#define RIVAL 50
int distSharpRigh;
int distSharpLeft;

// Variables y constantes para los motores
#define PIN_MOTOR_MR1 22 //DIR
#define PIN_MOTOR_MR2PWM 21 //PWM
#define PIN_MOTOR_ML1 19 //DIR
#define PIN_MOTOR_ML2PWM 18 //PWM
#define SEARCH_SPEED 100
#define ATTACK_SPEED 250
#define ATTACK_SPEED_SNAKE 250
#define AVERAGE_SPEED 200
int righSpeed = 200;
int leftSpeed = 200;

//Pines para los botones
#define PIN_BUTTON_START 34
bool boton_start;
#define PIN_BUTTON_STRATEGY 35

// variables y constantes para la pantalla oled
#define ANCHO 128     // reemplaza ocurrencia de ANCHO por 128
#define ALTO 64       // reemplaza ocurrencia de ALTO por 64
#define OLED_RESET 4      // necesario por la libreria pero no usado
//<------------------------------------------------------------------------------------------------------------->//
//Instanciamos todos los objetos del robot
Adafruit_SSD1306 oled(ANCHO, ALTO, &Wire, OLED_RESET);  // instancio la pantalla oled con una funcion de la libreria de adafruit

Motor *mDer = new Motor(PIN_MOTOR_MR1, PIN_MOTOR_MR2PWM, righSpeed);
Motor *mIzq = new Motor(PIN_MOTOR_ML1, PIN_MOTOR_ML2PWM, leftSpeed);

Tatami *rightTatami = new Tatami(PIN_SENSOR_TATAMI_DER);
Tatami *LeftTatami = new Tatami(PIN_SENSOR_TATAMI_IZQ);

Sharp *sharpRight = new Sharp(PIN_SENSOR_DISTANCIA_DERECHO);
Sharp *sharpLeft = new Sharp(PIN_SENSOR_DISTANCIA_IZQUIERDO);

Button *selectStrategy = new  Button(PIN_BUTTON_STRATEGY);
Button *start = new  Button(PIN_BUTTON_START);
//<------------------------------------------------------------------------------------------------------------->//
//Funciones para indicar el lado del giro del motor y su velocidad
void forward()
{
  mDer->SetVelocidad(righSpeed);
  mIzq->SetVelocidad(leftSpeed);
  mDer->Forward();
  mIzq->Forward();
}

void backward()
{
  mDer->SetVelocidad(righSpeed);
  mIzq->SetVelocidad(leftSpeed);
  mDer->Backward();
  mIzq->Backward();
}

void left()
{
  mDer->SetVelocidad(righSpeed);
  mIzq->SetVelocidad(leftSpeed);
  mDer->Forward();
  mIzq->Backward();
}


void right()
{
  mDer->SetVelocidad(righSpeed);
  mIzq->SetVelocidad(leftSpeed);
  mDer->Backward();
  mIzq->Forward();
}

void stop()
{
  mDer->SetVelocidad(0);
  mIzq->SetVelocidad(0);
  mDer->Stop();
  mIzq->Stop();
}
//<------------------------------------------------------------------------------------------------------------->//
//Con el enum reemplazamos los casos de la maquina de estado por palabras descriptivas para mejor interpretacion del codigo
enum strategy
{
  MENU,
  SNAKE,
  RONALDINHO,
  VENI_VENI,
  RIVER,
  SAN_LORENZO
};
int strategy = MENU;
int secondaryStrategy = RIVER;
//<------------------------------------------------------------------------------------------------------------->//
enum snake
{
  STANDBY_SNAKE,
  SEARCH_SNAKE,
  TURN_RIGHT_SNAKE,
  TURN_LEFT_SNAKE,
  TATAMI_LIMIT_SNAKE,
  ATTACK_SNAKE
};
int snake = STANDBY_SNAKE;
//Maquina de estados para la estrategia de serpiente
void Snake()
{
    switch (snake)
    {
    case STANDBY_SNAKE:
    {
        boton_start = start->GetIsPress();
        if (!boton_start) 
        {
          delay(5000);
          snake = SEARCH_SNAKE;
        } 
        else 
        {
          stop();
        }
        break;
      }

    case SEARCH_SNAKE:
    {
        righSpeed = SEARCH_SPEED;
        leftSpeed = SEARCH_SPEED;
        right();
        if(leftTatamiRead < 250 || righTatamiRead < 250) snake = TATAMI_LIMIT_SNAKE;
        if(distSharpRigh <= RIVAL && distSharpLeft > RIVAL) snake = TURN_RIGHT_SNAKE;
        if(distSharpRigh > RIVAL && distSharpLeft <= RIVAL) snake = TURN_LEFT_SNAKE;
        if(distSharpRigh <= RIVAL && distSharpLeft <= RIVAL) snake = ATTACK_SNAKE;
    }

    case TURN_RIGHT_SNAKE:
    {
        righSpeed = SEARCH_SPEED;
        leftSpeed = SEARCH_SPEED;
        right();
        if(leftTatamiRead < 250 || righTatamiRead < 250) snake = TATAMI_LIMIT_SNAKE;
        if(distSharpRigh > RIVAL && distSharpLeft > RIVAL) snake = SEARCH_SNAKE;
        if(distSharpRigh > RIVAL && distSharpLeft <= RIVAL) snake = TURN_LEFT_SNAKE;
        if(distSharpRigh <= RIVAL && distSharpLeft <= RIVAL) snake = ATTACK_SNAKE;
    }

    case TURN_LEFT_SNAKE:
    {
        righSpeed = SEARCH_SPEED;
        leftSpeed = SEARCH_SPEED;
        left();
        if(leftTatamiRead < 250 || righTatamiRead < 250) snake = TATAMI_LIMIT_SNAKE;
        if(distSharpRigh > RIVAL && distSharpLeft > RIVAL) snake = SEARCH_SNAKE;
        if(distSharpRigh <= RIVAL && distSharpLeft > RIVAL) snake = TURN_RIGHT_SNAKE;
        if(distSharpRigh <= RIVAL && distSharpLeft <= RIVAL) snake = ATTACK_SNAKE;
    }

    case ATTACK_SNAKE:
    {
        righSpeed = ATTACK_SPEED_SNAKE - (distSharpRigh);
        leftSpeed = ATTACK_SPEED_SNAKE - (distSharpLeft);
        forward();
        if(leftTatamiRead < 250 || righTatamiRead < 250) snake = TATAMI_LIMIT_SNAKE;
        if(distSharpRigh > RIVAL && distSharpLeft > RIVAL) snake = SEARCH_SNAKE;
        if(distSharpRigh <= RIVAL && leftTatamiRead > RIVAL) snake = TURN_RIGHT_SNAKE;
        if(distSharpRigh > RIVAL && distSharpLeft <= RIVAL) snake = TURN_LEFT_SNAKE;

    }

    case TATAMI_LIMIT_SNAKE: 
    {
    righSpeed = AVERAGE_SPEED;
    leftSpeed = AVERAGE_SPEED;
    backward();
    delay(300);
    snake = SEARCH_SNAKE;
    break;
    }

    }

}
//<------------------------------------------------------------------------------------------------------------->//
enum ronaldinho
{
  STANDBY_RONALDINHO,
  GO_FORWARD_RONALDINHO,
  OLEE_RONALDINHO,
  STOP_RONALDINHO,
  SWITCH_STRATEGY_RONALDINHO
};
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

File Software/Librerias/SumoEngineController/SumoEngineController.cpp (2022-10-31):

#include "SumoEngineController.h"

Engine::Engine(int dir, int pwm)
{
    pinDirection = dir;
    pinPwm = pwm;

    pinMode(pinDirection, OUTPUT);
    pinMode(pinPwm, OUTPUT);
}
void Engine::Forward(int speed)
{
    speed = speed;
    digitalWrite(pinDirection, HIGH);
    analogWrite(pinPwm, speed);
}
void Engine::Backward(int speed)
{
    speed = speed;
    analogWrite(pinPwm, 0);
    digitalWrite(pinDirection, LOW);
    analogWrite(pinPwm, speed);
}
void Engine::Stop()
{
    digitalWrite(pinDirection, LOW);
    analogWrite(pinPwm, 0);
}


EngineController::EngineController(int dirRight, int pwmRight, int dirLeft, int pwmLeft)
{
    pinDirectionRight = dirRight;
    pinPwmRihgt = pwmRight;
    pinDirectionLeft = dirLeft;
    pinPwmLeft = pwmLeft;
    engineRight = new Engine(pinDirectionRight, pinPwmRihgt);
    engineLeft = new Engine(pinDirectionLeft, pinPwmLeft);
}
void EngineController::Forward(int pwmRight, int pwmLeft)
{
    speedRight = pwmRight;
    speedLeft = pwmLeft;
    engineRight->Forward(speedRight);
    engineLeft->Forward(speedLeft);
}
void EngineController::Backward(int pwmRight, int pwmLeft)
{
    speedRight = pwmRight;
    speedLeft = pwmLeft;
    engineRight->Backward(speedRight);
    engineLeft->Backward(speedLeft);
}
void EngineController::Right(int pwmRight, int pwmLeft)
{
    speedRight = pwmRight;
    speedLeft = pwmLeft;
    engineRight->Backward(speedRight);
    engineLeft->Forward(speedLeft);
}
void EngineController::Left(int pwmRight, int pwmLeft)
{
    speedRight = pwmRight;
    speedLeft = pwmLeft;
    engineRight->Forward(speedRight);
    engineLeft->Backward(speedLeft);
}
void EngineController::Stop()
{
    engineRight->Stop();
    engineLeft->Stop();
}

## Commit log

2022-08-27 Add the folders
    [2020 - Sumo - NANO.kicad_pcb, 2020 - Sumo - NANO.kicad_sch, 2020 - Sumo - NANO.sch]
2022-08-27 el robot ahora detecta sensores de piso y gira
2022-08-27 Realice POO de motores
2022-08-27 Realice el POO de sensores anda bien
2022-08-27 Correciones sugeridas por angel y agregue class button y buzzer
2022-08-27 Realice la maquina de estados pero tengo problemas
2022-08-29 maquina de estados y todos los chiches
2022-09-01 contine switch
2022-09-03 agregue la prueba de sensores tatami
2022-09-03 hice test de tatami
2022-09-03 El robot lo probamos y anda, no andan los sensores tatami pero creemos que por hardware
2022-09-03 probando como detecta el sensor
2022-09-03 ahora si andan los sensores y todo :)
2022-09-09 cambios para probar los dos sharp
2022-09-24 Pase las clases a librerias y termine la primera estrategia
2022-09-24 pase las clases a librerias y termine la estrategia 1 del codigo
2022-09-26 agregue los codigos para probar cada sensor
2022-09-26 correccion de errores
2022-10-03 Estuve realizando los test de sensores y estan okey
2022-10-05 Hice pruebas pero el codigo que hizo eze no anda nada bien
2022-10-07 Pruebas de Sami con exitos
2022-10-08 cambios para llevar a UTN
2022-10-10 probando post competencia UTN falla de boton y no posee strategy
2022-10-11 haciendo placa nueva de sami con esp32
    [PCB V3 - Leandro.kicad_pcb, PCB V3 - Leandro.kicad_sch]
2022-10-12 termine la placa hay que ver que dice bustos
    [PCB V3 - Leandro.kicad_pcb, PCB V3 - Leandro.kicad_sch]
2022-10-12 corregi algo quevi de gnd
    [PCB V3 - Leandro.kicad_pcb]
2022-10-12 falta la correccion de Bustos y diseñar el svg
    [PCB V3 - Leandro.kicad_pcb, PCB V3 - Leandro.kicad_sch]
2022-10-12 falta los svg y que me corrija bustos
2022-10-13 placa para fabricar ya
    [PCB V3 - Leandro.kicad_pcb, PCB V3 - Leandro.kicad_sch]
2022-10-13 placa lista con 3d
    [PCB V3 - Leandro.kicad_pcb]
2022-10-14 Realizando pruebas con el button , hace ruido todasvia
2022-10-15 Ordenando pines respecto del esp32
2022-10-16 REGULANDO LIBRERIA DE SENSOR SHARP
2022-10-16 actualizando pines de ESP32
2022-10-16 corrigiendo cosas que me dijo bustos
    [SamiEstrategia.ino]
2022-10-17 empece el codigo definitivo de Sami con varias estrategias
2022-10-17 codigo por mi parte listo falta probar motoresw pero en mi pc no compilaaaa
2022-10-17 ordene todo mejor y modifique una variable de las librerias para declararla dentro de la clase
2022-10-17 separe la estrategias en codigos aparte para probar una por una
2022-10-18 agregue el menu del display oled para acceder a cada estrategia
2022-10-18 Probe A Sami asi nomas y no me andan BIEN Los sensores lpm el resto joya
2022-10-18 cambios de sch
    [PCB V3 - Leandro.kicad_sch]
2022-10-26 agregue la clase de controlador de motores y demas mejores sugeridas por fon
2022-10-26 Cambios realizados para competir en La Salle
2022-10-31 arreglos en la prueba de cada estrategia
    [SamiEstragiaRonaldinho.ino, SamiEstragiaSnake.ino, SamiEstrategiaRiver.ino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]
2022-11-01 codigo funcional y probado con los giros de reposicionamiento
2022-11-01 pruebas realizadas antes de ITATI
2022-11-05 agregue la estrategia agresiva
2022-11-08 areglo de un par de errores de sintanxis
    [SamiVdefFinalLNR.ino]
2022-11-11 cambios en el codigo
2022-11-11 empece con el codigo de Ryo
2022-11-23 codigo de Ryo usado en antes de la final nacional en las pruebas del dia anterior
